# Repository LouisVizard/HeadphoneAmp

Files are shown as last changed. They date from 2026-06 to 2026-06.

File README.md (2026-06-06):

# 🎸 Guitar Headphone Amplifier

**A compact, single-supply headphone amplifier for electric guitar, built around a paralleled NE5532 output stage**



[]()
[]()


---

## 📌 Overview

The **Guitar Headphone Amplifier** is a custom PCB designed to drive low-impedance headphones directly from an electric guitar signal — no computer audio interface required. The board operates from a single 9V supply using a virtual ground at VCC/2, and features a paralleled op-amp output stage capable of cleanly driving 32Ω loads without a discrete transistor buffer stage.

> Hardware design is complete. The board was designed, simulated, and laid out in full at Cornell University in 2022.

---

## ⚡ Specifications

| Parameter | Value |
|---|---|
| **Op-Amp** | NE5532 (×4, paralleled output stage) |
| **Power Supply** | 9V DC via barrel jack |
| **Input** | Electric guitar, mono |
| **Output** | 3.5mm headphone jack |
| **Volume Control** | 100kΩ potentiometer |
| **PCB Stackup** | 2-layer, KiCAD |

---

## 🏗️ Signal Chain

```
┌──────────────┐     ┌──────────────────┐     ┌──────────────────────────┐     ┌──────────────┐     ┌──────────────┐
│              │     │                  │     │                          │     │              │     │              │
│  Guitar In   │────▶│  Input Buffer    │────▶│  ×4 Parallel Output      │────▶│  Volume Pot  │────▶│  Headphone   │
│  (J3)        │     │  U1A — NE5532    │     │  Stage  U2–U3 — NE5532   │     │  RV1 100kΩ   │     │  Out (J1)    │
│              │     ├──────────────────┤     │                          │     │              │     │              │
│              │     │  Active Filter   │     │                          │     │              │     │              │
│              │     │  U1B — NE5532    │     │                          │     │              │     │              │
└──────────────┘     └──────────────────┘     └──────────────────────────┘     └──────────────┘     └──────────────┘
```

A virtual ground at VCC/2 enables single-supply operation. Coupling capacitors block DC from the headphone output.

---

## 🔧 Design Details

### Op-Amp Selection — NE5532 over LM358

The initial design used an **LM358**. Transient simulation in LTSpice exposed a critical flaw: crossover distortion appearing at frequencies as low as 5–10 kHz. This notching artifact near the zero-crossing is clearly audible and disqualifies the LM358 from audio signal paths.

The pin-compatible **NE5532** was substituted and resolved the issue entirely:

- Industry-standard audio op-amp with input voltage noise of **5 nV/√Hz**
- Significantly higher slew rate than the LM358
- Simulation confirmed clean, undistorted output across the full **20 Hz – 20 kHz** audio band

### Paralleled Output Stage

Driving 32Ω headphones requires more output current than a single op-amp section can supply without distortion. Rather than adding a discrete BJT output stage, **four NE5532 sections are wired in parallel**:

- Multiplies available output current by **4×**
- Averages individual op-amp noise contributions
- Eliminates bias complexity associated with class-AB transistor stages

### PCB Layout

The 2-layer board was laid out in KiCAD with the following considerations:

- Copper pour ground plane on the bottom layer for noise rejection
- Decoupling capacitors placed directly at each op-amp supply pin
- Ferrite bead (FB1) and protection diode (D2) at the audio output
- All panel connectors (barrel jack, potentiometer, audio jacks) placed at board edges for clean enclosure mounting

---

## 🗺️ Roadmap

- [x] Schematic capture and component selection
- [x] LTSpice simulation — LM358 vs NE5532 comparison
- [x] PCB layout and design rule check
- [ ] Bench measurement of THD+N and SNR; comparison against simulation
- [ ] Baxandall tone control in place of simple volume potentiometer
- [ ] Laser-cut or 3D-printed enclosure

---

## 🛠️ Tech Stack

| Layer | Technology |
|---|---|
| **Schematic & PCB** | KiCAD |
| **Simulation** | LTSpice |
| **Core Component** | NE5532 audio op-amp |

---

## 👤 Author

**Luis Martinez**





---

*Built with KiCAD · LTSpice · NE5532*

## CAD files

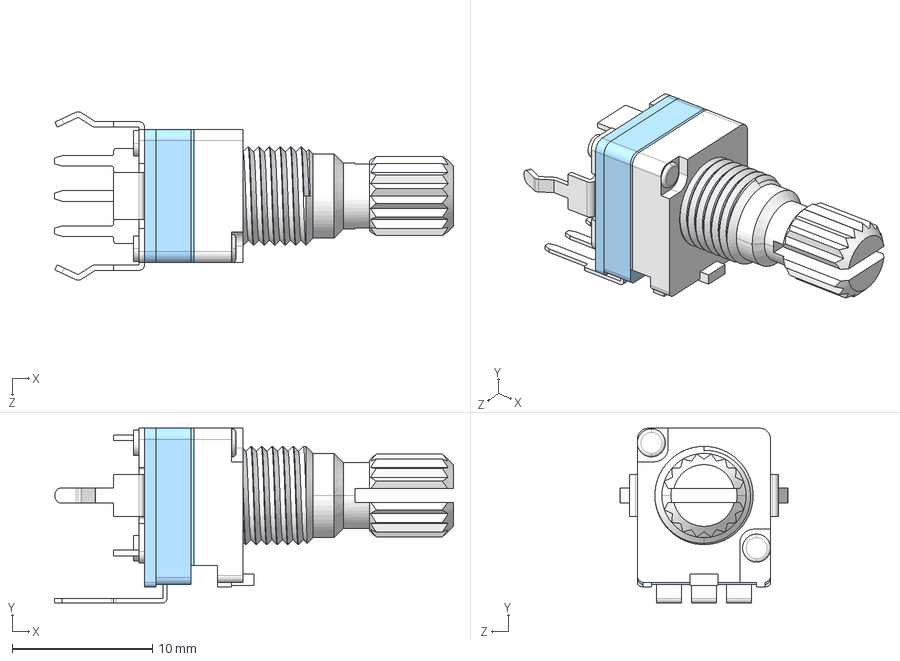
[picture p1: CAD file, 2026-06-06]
3D_Models/PTN091-V100115K1B.stp
28.4 x 12.4 x 12.0 mm
FIX_PLATE
BUSHING_5-V_V1
PTN091-V_HOUSING
K_SHAFT_L15

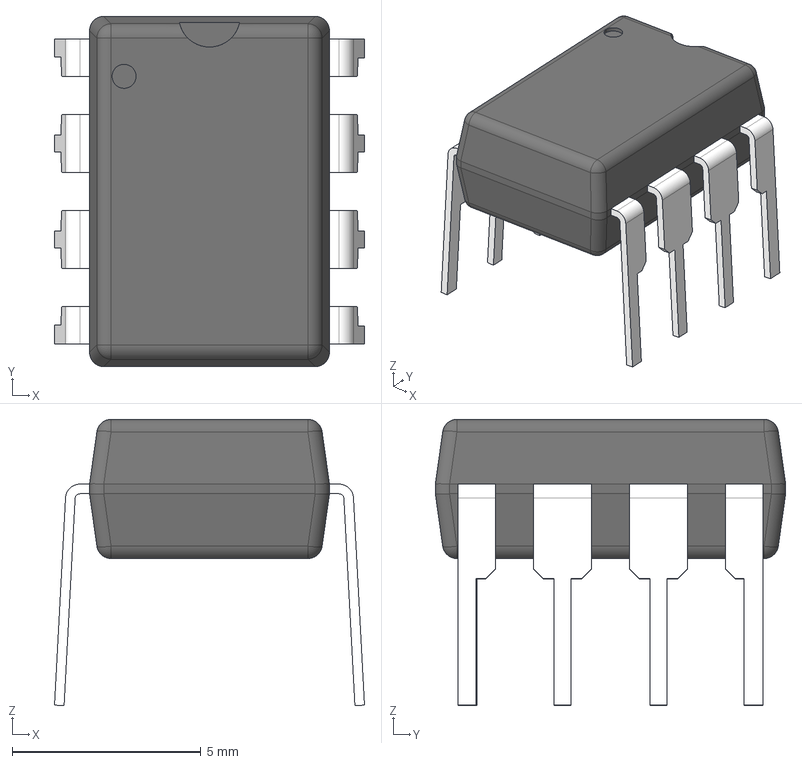
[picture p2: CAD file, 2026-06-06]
3D_Models/LM358AN_NOPB.stp
8.20 x 9.27 x 7.58 mm
BODY_P0008A
LEAD_P0008A x 4
LD_LHALF_P0008A x 2
LD_RHALF_P0008A x 2

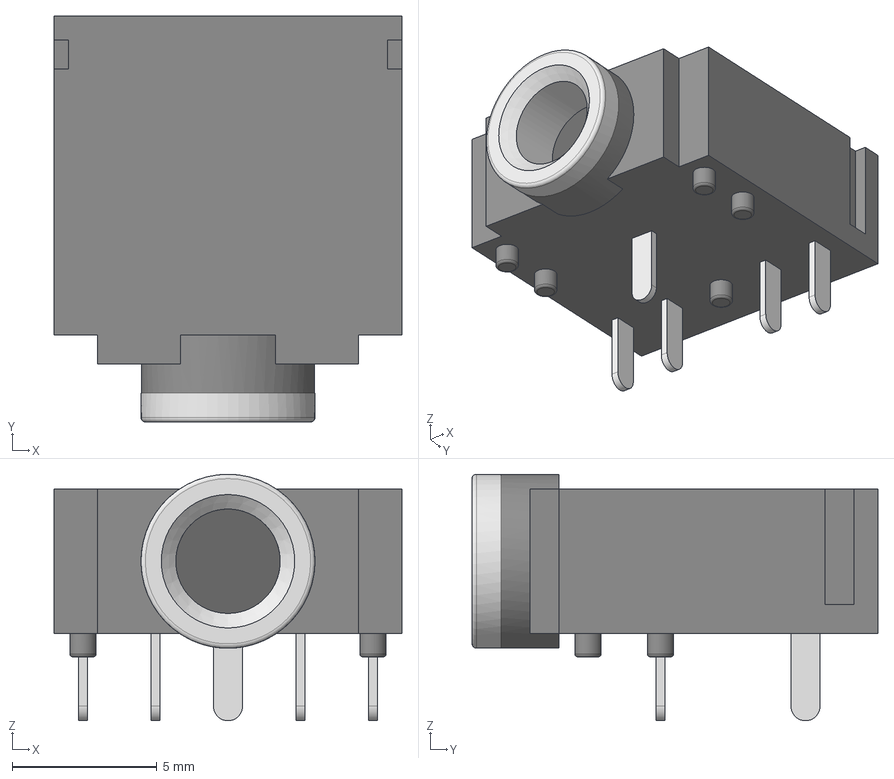
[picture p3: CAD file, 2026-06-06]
3D_Models/PRT-08032.stp
12.0 x 14.0 x 8.50 mm

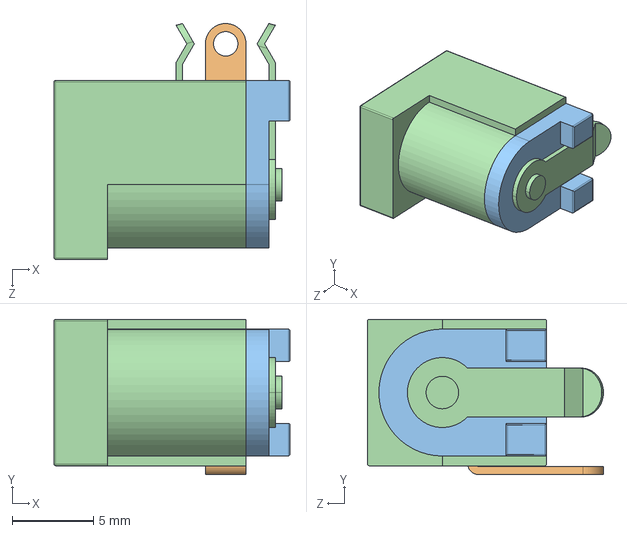
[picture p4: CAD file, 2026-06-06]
3D_Models/PRT-00119.stp
14.5 x 9.55 x 14.5 mm

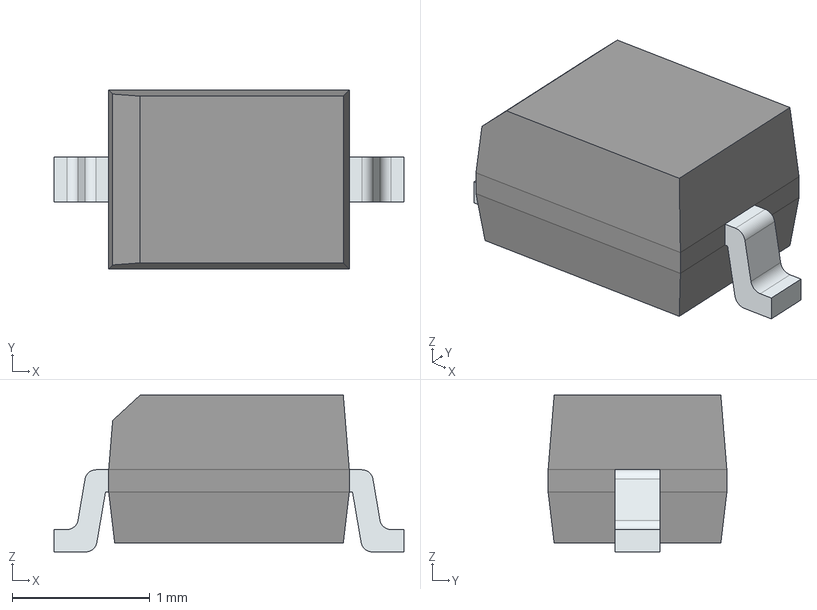
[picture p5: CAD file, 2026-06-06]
3D_Models/CDSOD323-T03SC.stp
2.54 x 1.30 x 1.14 mm
FilletPinL
FilletPinR

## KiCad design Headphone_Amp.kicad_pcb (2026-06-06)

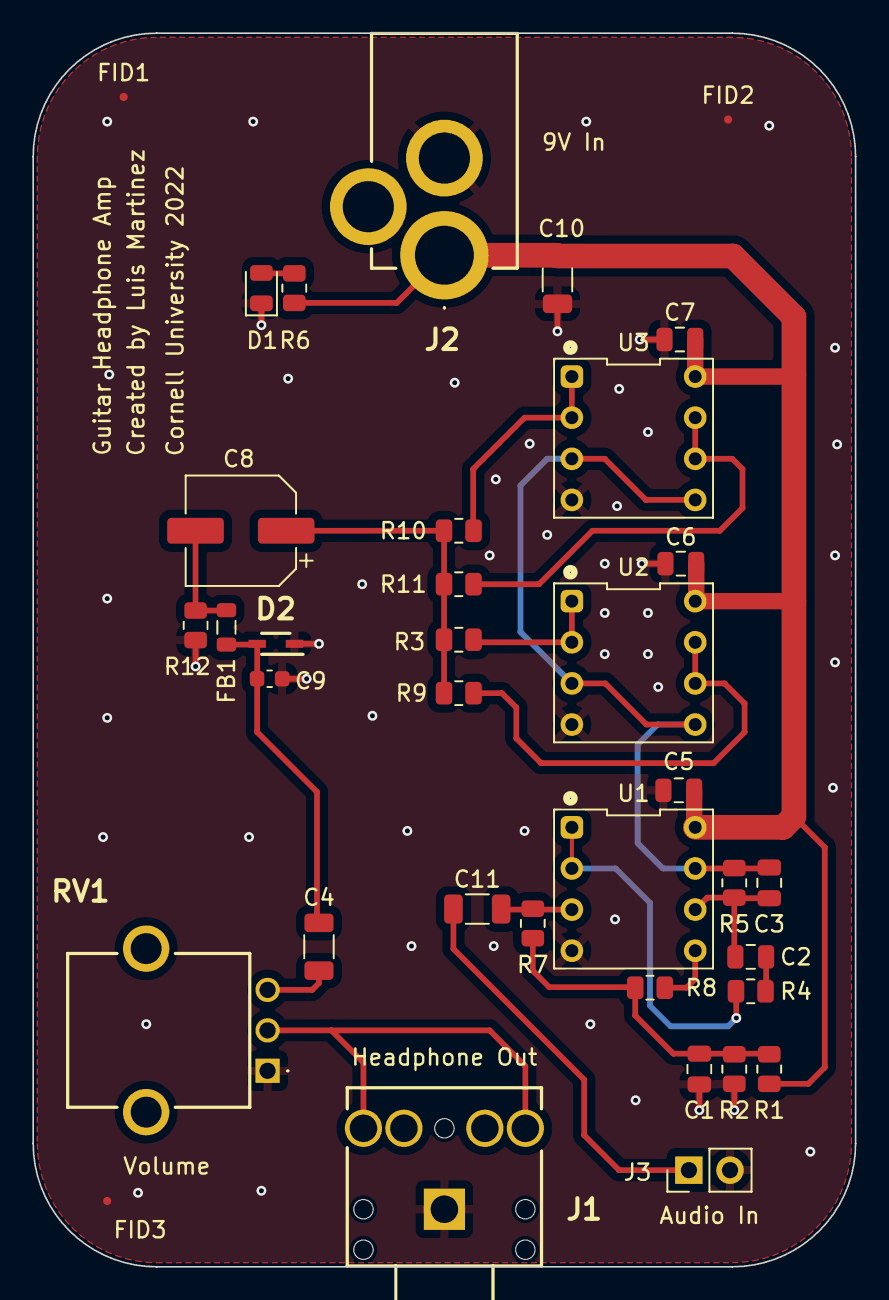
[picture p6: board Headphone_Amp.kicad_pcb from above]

Board: 2 copper layers, 50.8 x 76.2 mm, 36 parts (0 on the bottom side), 20 nets.

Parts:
C1: 4.7uF; C_0805_2012Metric
C2: 390nF; C_0805_2012Metric
C3: 51pF; C_0805_2012Metric
C4, C11: 10uF; C_1206_3216Metric
C5, C6, C7: 0.1uF; C_0805_2012Metric
C8: 100uF; CP_Elec_6.3x5.9
C9: 30pF; C_0603_1608Metric
C10: 22uF; C_1206_3216Metric
D1: APT2012LSECK/J3-PRV; D_0805_2012Metric
D2: CDSOD323-T03SC
FB1: 120R; L_0805_2012Metric
FID1, FID2, FID3: Fiducial; Fiducial_0.5mm_Mask1mm
J1: PRT-08032; PRT08032
J2: PRT-00119; PRT00119
J3: Conn_01x02; PinHeader_1x02_P2.54mm_Vertical
R1, R2, R4: 10k; R_0805_2012Metric
R3, R9, R10, R11: 1; R_0805_2012Metric
R5: 100k; R_0805_2012Metric
R6: 3.6k; R_0805_2012Metric
R7, R8: 470k; R_0805_2012Metric
R12: 1.8k; R_0805_2012Metric
RV1: 100k; PTN091V100115K1B
U1, U2, U3: NE5532; NE5532_8DIP

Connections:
AUDIO_FILT: C3.2, R5.2, U1.7, U2.3 (+), U2.5 (+), U3.3 (+), U3.5 (+)
AUDIO_OUT: C4.1, C9.1, D2.2 (A2), FB1.2
GND: C1.2, C5.1, C6.1, C7.1, C9.2, C10.2, D1.1 (K), D2.1 (A1), J1.G, J2.2, J3.2, R2.2, R12.2, RV1.1, U1.4 (V-), U2.4 (V-), U3.4 (V-)
unnamed: C2.1, R4.2
unnamed: C4.2, RV1.3
unnamed: C8.1, R3.2, R9.2, R10.2, R11.2
unnamed: C8.2, FB1.1, R12.1
unnamed: D1.2 (A), R6.2
unnamed: J1.S, J1.T, RV1.2
unnamed: C11.2, R7.2, U1.3 (+)
unnamed: R4.1, U1.1, U1.2 (-)
unnamed: R8.2, U1.5 (+)
unnamed: C2.2, C3.1, R5.1, U1.6 (-)
unnamed: R3.1, U2.1, U2.2 (-)
unnamed: R9.1, U2.6 (-), U2.7
unnamed: R10.1, U3.1, U3.2 (-)
unnamed: R11.1, U3.6 (-), U3.7
SIG_IN: C11.1, J3.1
VBias: C1.1, R1.2, R2.1, R7.1, R8.1
VCC: C5.2, C6.2, C7.2, C10.1, J2.1, R1.1, R6.1, U1.8 (V+), U2.8 (V+), U3.8 (V+)
